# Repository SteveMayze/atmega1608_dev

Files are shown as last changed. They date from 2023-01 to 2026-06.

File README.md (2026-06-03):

# ATMega1608 Dev KiCad Automation

This project includes release automation for fabrication deliverables.

The automation entrypoints are intentionally stored at repository root so GitHub Actions can discover workflows correctly.

## Current automation goal

When a Git tag matching `r#.#.#` is pushed (example: `r0.1.0`), GitHub Actions will:

1. Set the KiCad text variable `RELEASE` in the project file.
2. Generate Gerber and drill files using `kicad-cli`.
3. Write deliverables to `gerber/`.
4. Upload artifacts and attach a ZIP to the GitHub release.

## Files added for automation

- `.github/workflows/release-gerbers.yml`: Release workflow triggered by version tags.
- `scripts/generate_release_artifacts.py`: Single entrypoint script for local and CI generation.
- `release-artifacts.json`: User-editable release configuration, including Gerber include layers.
- `PROJECT_TRACKING.md`: Task and roadmap tracking.

## Local usage

### Prerequisites

- KiCad installed with `kicad-cli` available on PATH.
- Python 3.9+.

If `kicad-cli` is not on PATH, set:

- macOS/Linux: `export KICAD_CLI=/full/path/to/kicad-cli`
- Windows (PowerShell): `$env:KICAD_CLI="C:\\Path\\To\\kicad-cli.exe"`

### Configure Gerber include layers

Edit `release-artifacts.json` and set:

- `project.path`: Relative path to your KiCad `.kicad_pro` file.
- `gerber.include_layers`: Layers to include in Gerber export.

Example:

```json
{
	"project": {
		"path": "kicad/ATMega1608_Dev/ATMega1608_Dev.kicad_pro"
	},
	"gerber": {
		"include_layers": [
			"F.Cu",
			"B.Cu",
			"F.Mask",
			"B.Mask",
			"F.SilkS",
			"B.SilkS",
			"Edge.Cuts"
		]
	}
}
```

This list is passed to `kicad-cli` as the `--layers` argument.
The script validates configured layer names against the board's `(layers ...)` list in the PCB file and fails early if any configured layer is invalid.

### Generate Gerbers for a release tag

```bash
python3 scripts/generate_release_artifacts.py --tag r0.1.0
```

This will update `RELEASE` to `0.1.0` and generate output in `gerber/`.

If needed, `--project` can still be passed to override `project.path` from config.

### Generate without updating `RELEASE`

```bash
python3 scripts/generate_release_artifacts.py --tag r0.1.0 --no-update-release-variable
```

### Dry run (no generation, just prints commands)

```bash
python3 scripts/generate_release_artifacts.py --tag r0.1.0 --dry-run
```

## Release trigger

Push a release tag:

```bash
git tag r0.1.0
git push origin r0.1.0
```

The workflow runs automatically for tags matching `r*.*.*`.

## CI KiCad version

This project currently targets a KiCad 10 board file format, so CI installs KiCad nightly in
GitHub Actions before generating artifacts.

The workflow uses `release-artifacts.json` for project discovery and does not hardcode the
`.kicad_pro` location.

## Future extension

The script already includes optional flags for future needs:

- `--schematic-pdf` to export schematic PDF.
- `--board-pdf` to export PCB layout PDF.

These are optional now and can be enabled later in the workflow.

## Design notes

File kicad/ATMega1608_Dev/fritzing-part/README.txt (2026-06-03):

KiCad2Fritzing conversion output
Source board: /Volumes/SanDisk/PCB-Archive/atmega1608_dev/kicad/ATMega1608_Dev/ATMega1608_Dev.kicad_pcb

Generated files:
  Intermediate model: board_model.json
  Connector model: fritzing_connectors.json
  Fritzing part definition: ATMega1608_Dev_260528_01d.fzp
  SVG views: icon.svg, breadboard.svg, schematic.svg, pcb.svg
  Fritzing shareable part: ATMega1608_Dev_260528_01d.fzpz (ready to import)
  Validation report: artifact_validation.json

To import into Fritzing:
  1. Open Fritzing
  2. Right-click in the 'Mine' bin → Import...
  3. Select ATMega1608_Dev_260528_01d.fzpz

Next step: refine SVG geometry from real board footprint data.

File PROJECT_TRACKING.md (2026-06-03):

# PROJECT_TRACKING

## Objective

Create a reusable release automation pattern for this KiCad project that can later be moved into a project template.

## Scope (current)

- [x] Add a single script entrypoint for fabrication deliverables.
- [x] Generate Gerber files with `kicad-cli`.
- [x] Generate drill files with `kicad-cli`.
- [x] Write outputs to `gerber/`.
- [x] Trigger generation from Git tag pattern `r#.#.#`.
- [x] Propagate release version from tag to KiCad text variable `RELEASE`.
- [x] Add user-configurable Gerber include layer list via JSON config.

## Scope (next)

- [ ] Export schematic PDF during release automation.
- [ ] Export PCB layout PDF during release automation.
- [ ] Add KiCad DRC/ERC checks in CI before artifact generation.
- [ ] Standardize artifact naming conventions for manufacturing handoff.

## Template readiness tasks

- [x] Move automation files into repository root locations required by GitHub Actions.
- [x] Parameterize project file name discovery for repositories where the KiCad project is not at root.
- [ ] Add a template onboarding checklist (toolchain, paths, variables).
- [ ] Document compatibility matrix for KiCad versions used in CI.

## Notes

- The source of truth for release version is the Git tag (`r#.#.#`).
- The script maps this tag to `RELEASE=#.#.#` in the `.kicad_pro` file before generation.
- This keeps release identity in one place while preserving KiCad text variable usage.

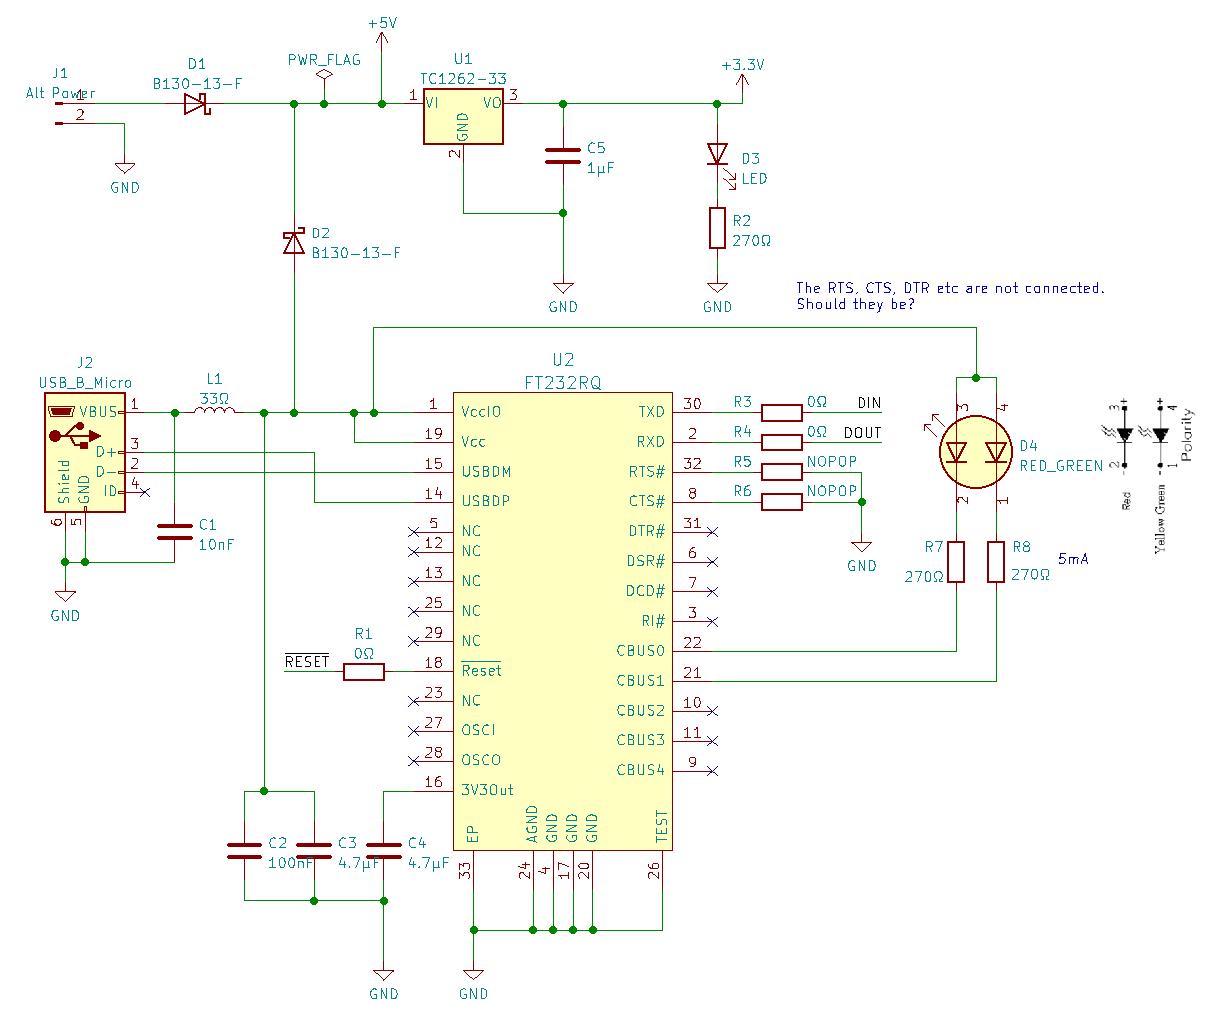
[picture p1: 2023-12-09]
kicad/doc/USART-Troubleshooting/FT232-Schematic.png

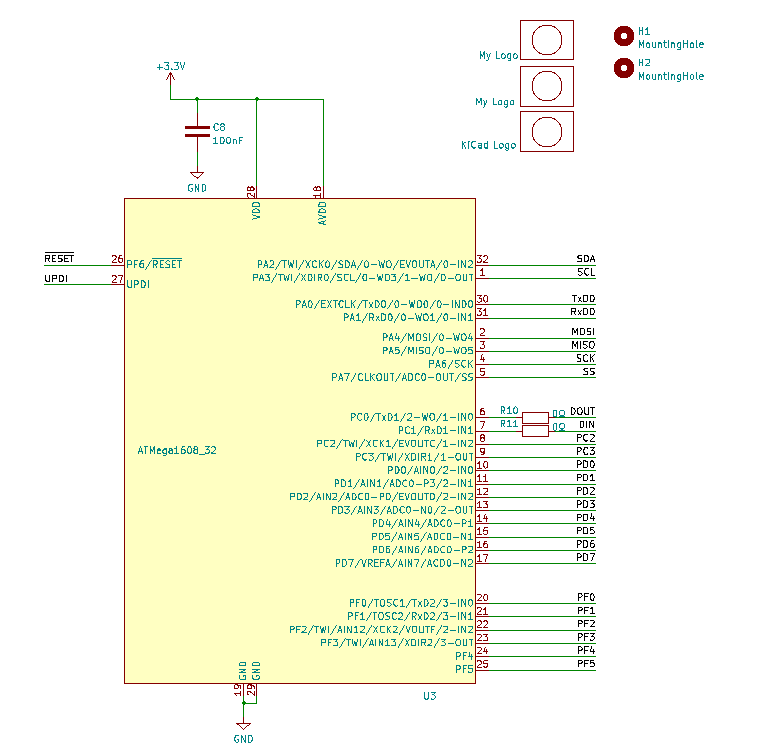
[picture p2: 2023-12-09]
kicad/doc/USART-Troubleshooting/MCU-Schematic.png

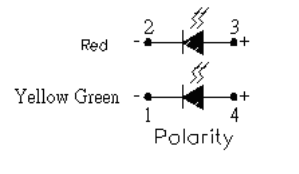
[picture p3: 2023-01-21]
kicad/doc/LED_Dual_KKAA.png

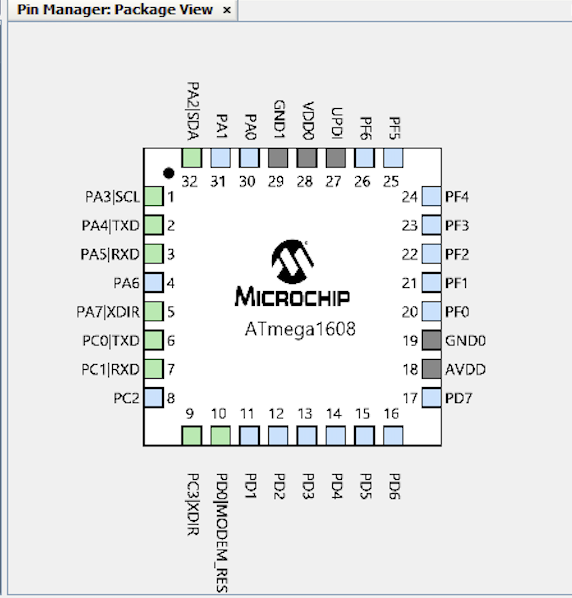
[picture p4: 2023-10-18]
kicad/doc/Atmega1608-Pins.png

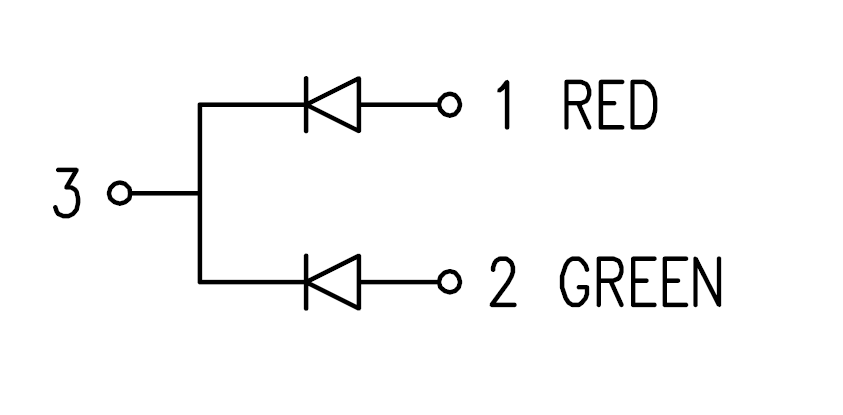
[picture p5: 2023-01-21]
kicad/doc/RGK_LED.png

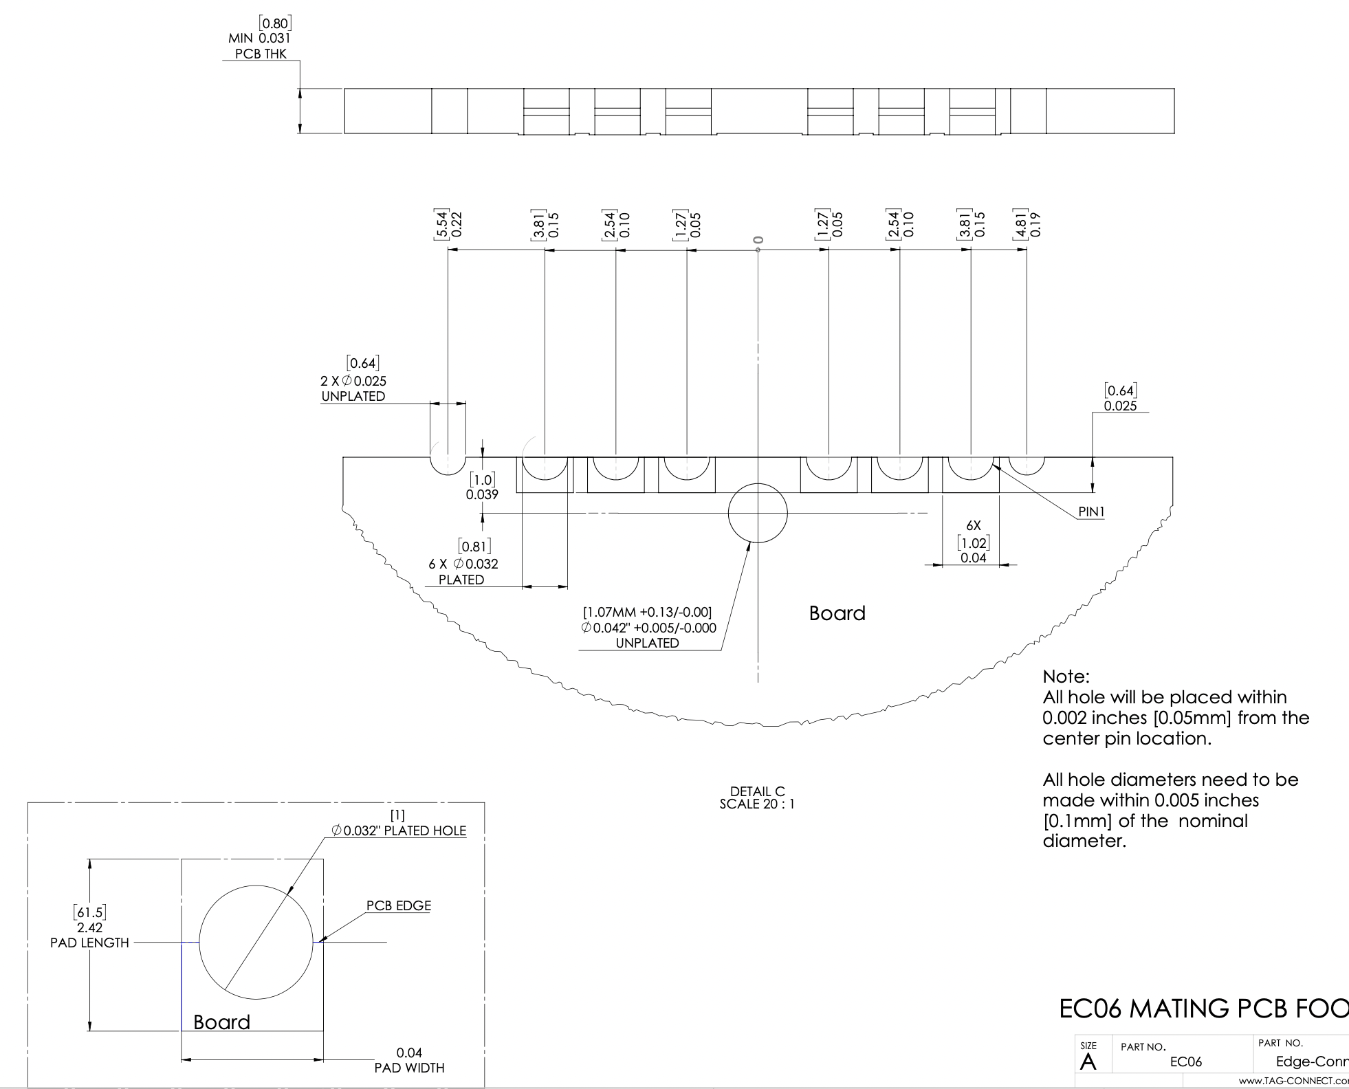
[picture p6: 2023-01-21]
kicad/doc/Screenshot 2022-12-26 at 10.46.26.png

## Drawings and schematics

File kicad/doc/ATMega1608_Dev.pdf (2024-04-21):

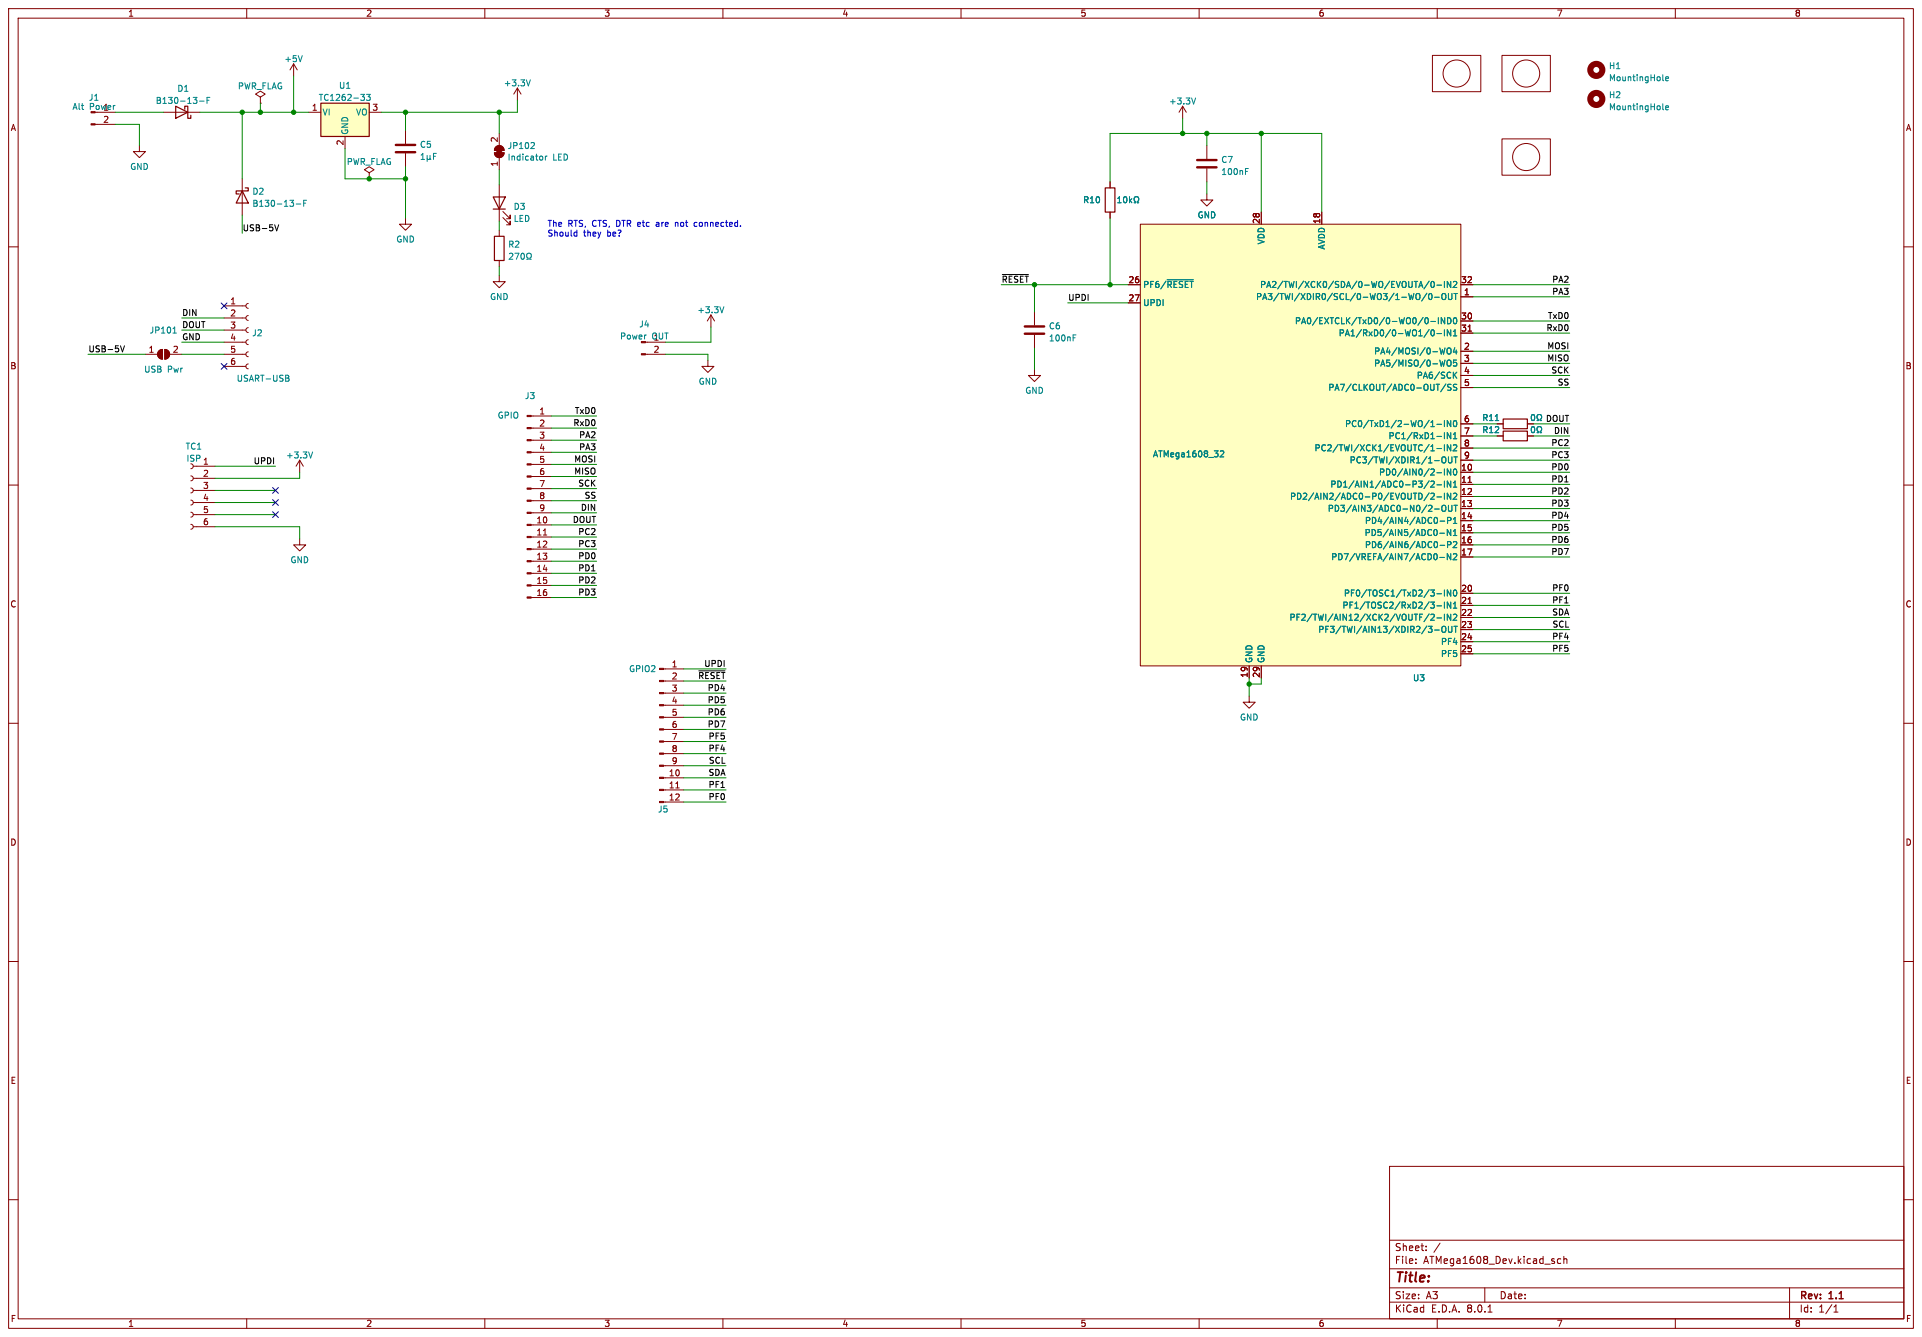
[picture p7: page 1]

Id: 1/1 Title: File: ATMega1608_Dev.kicad_sch Sheet: /

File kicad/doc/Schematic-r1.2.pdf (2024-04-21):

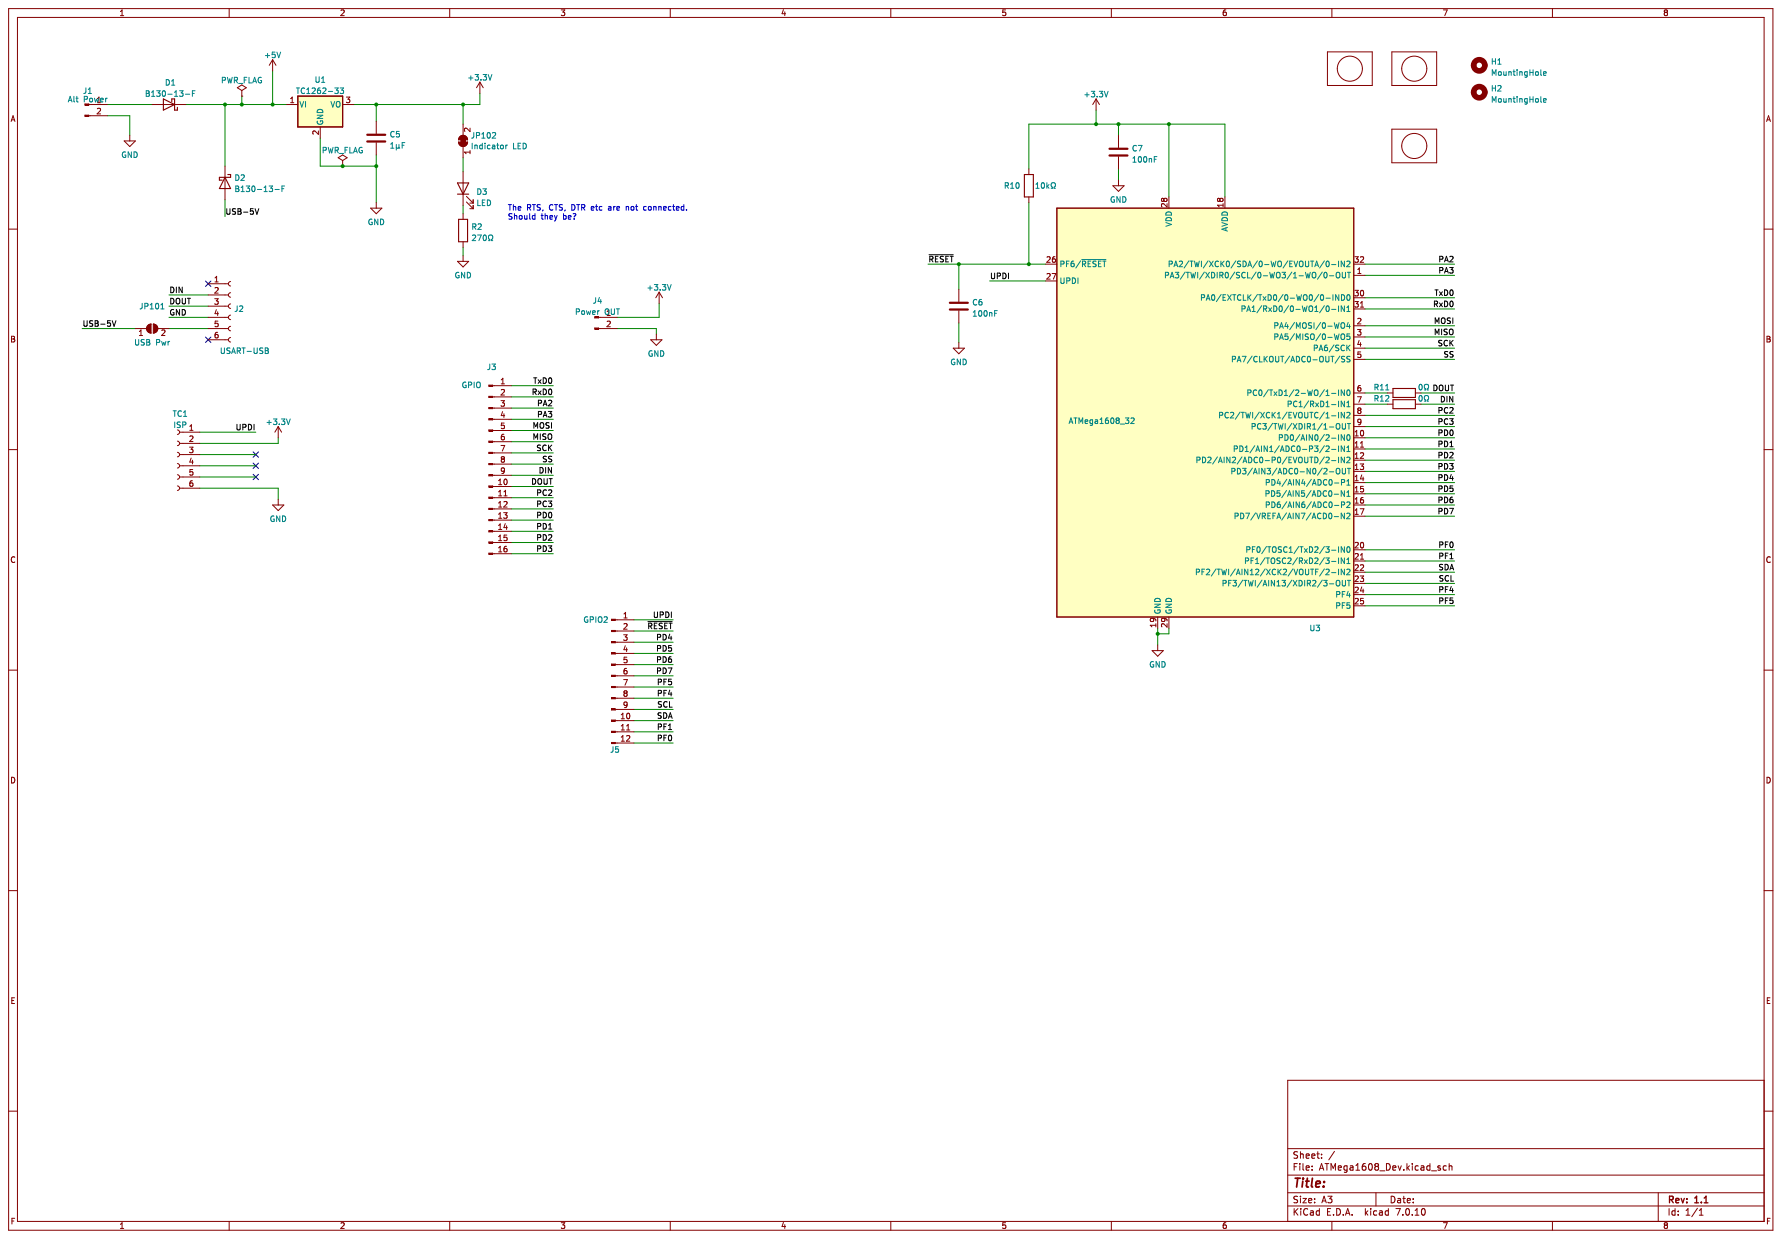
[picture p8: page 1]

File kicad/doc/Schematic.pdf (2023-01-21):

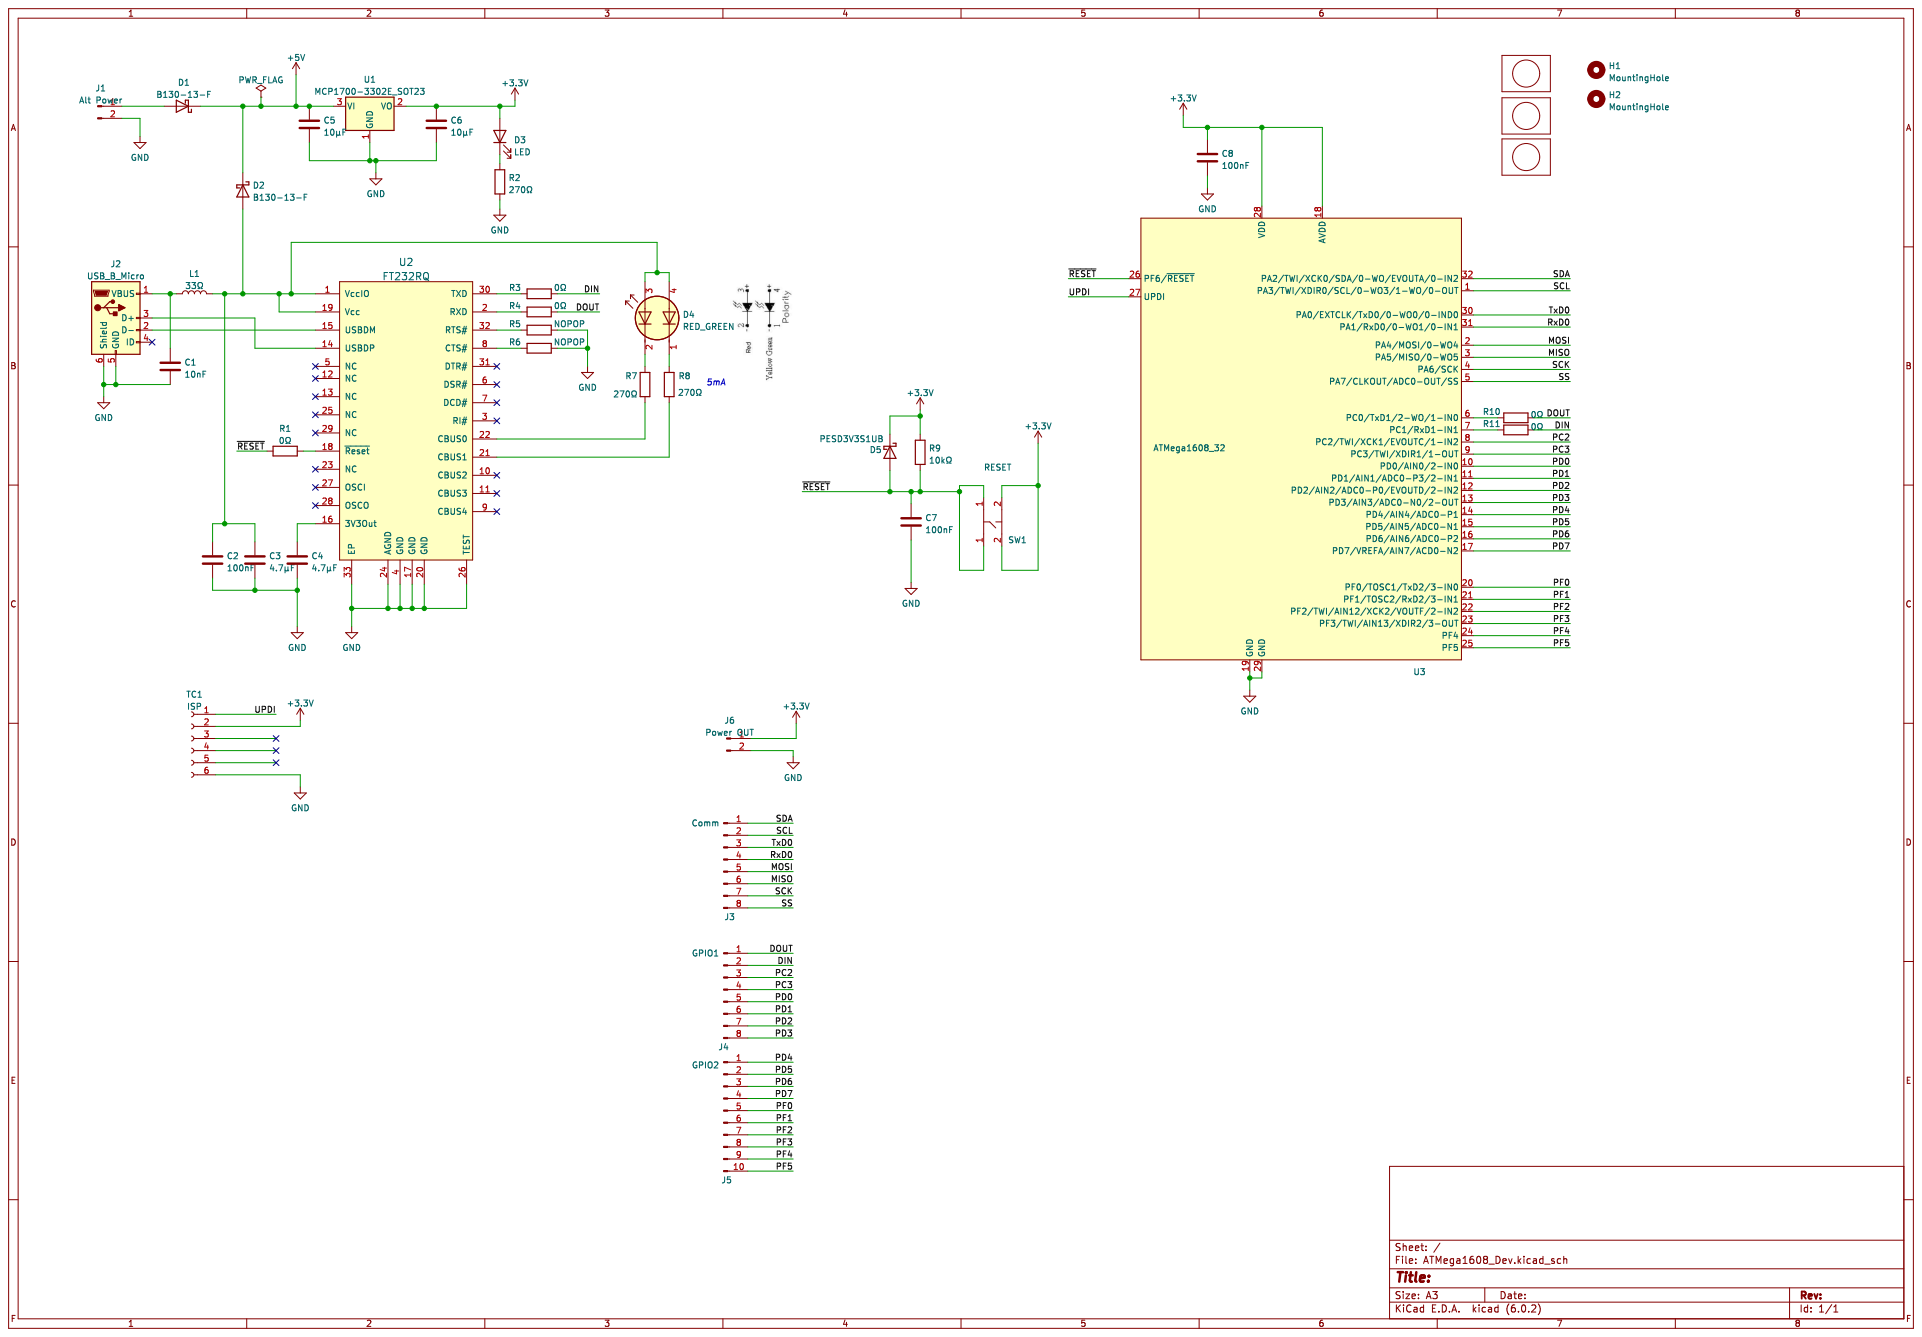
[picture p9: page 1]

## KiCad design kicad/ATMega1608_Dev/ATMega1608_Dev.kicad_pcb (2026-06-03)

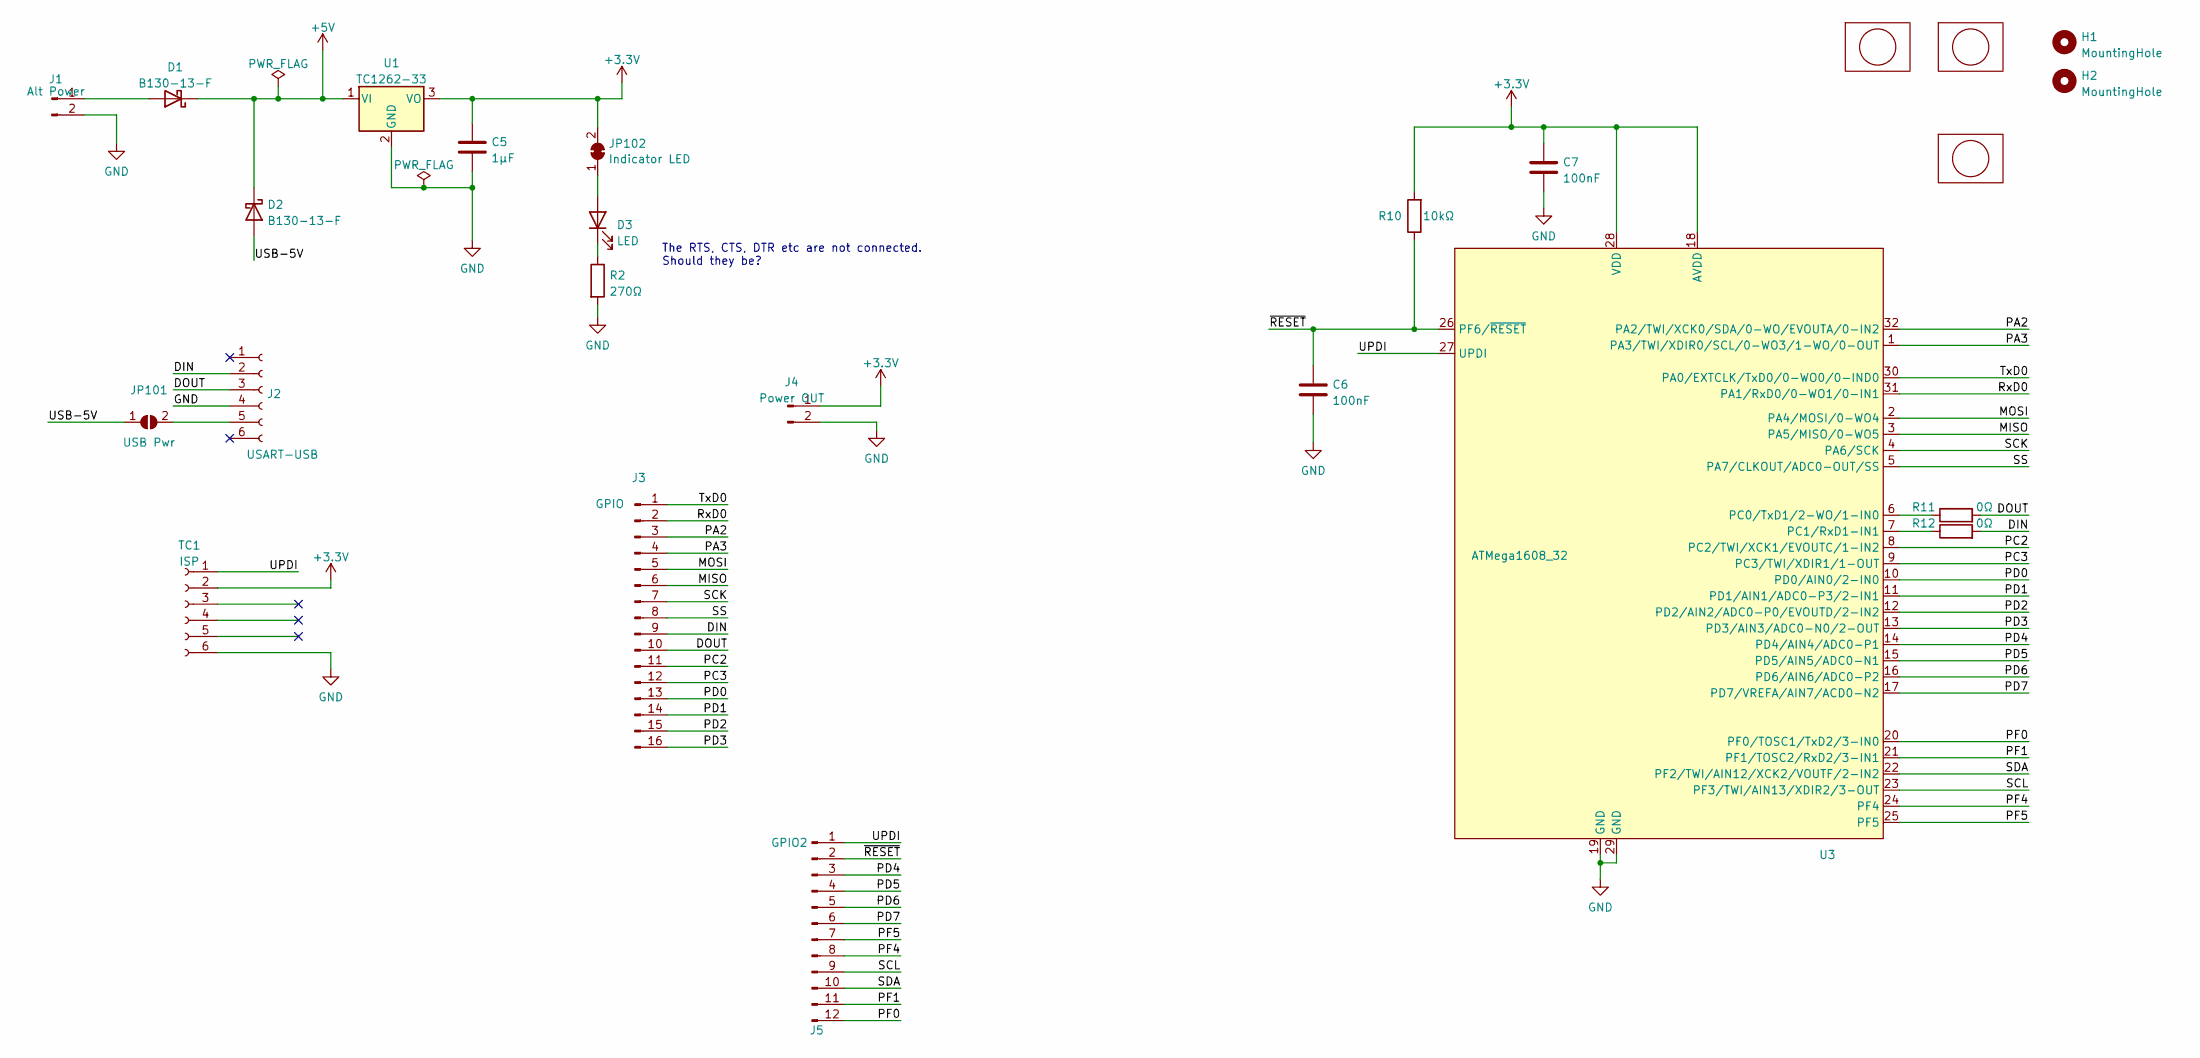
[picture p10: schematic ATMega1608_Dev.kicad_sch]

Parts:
C5: 1μF; C_0805_2012Metric_Pad1.18x1.45mm_HandSolder
C6, C7: 100nF; C_0805_2012Metric
D1, D2: B130-13-F; D_SMA; MPN B130-13-F
D3: LED; LED_0805_2012Metric
H1, H2: MountingHole; MountingHole_2.7mm_M2.5
J1: Alt Power; PinHeader_1x02_P2.54mm_Vertical
J2: USART-USB; PinSocket_1x06_P2.54mm_Vertical
J3: GPIO; PinHeader_1x16_P2.54mm_Vertical
J4: Power OUT; PinHeader_1x02_P2.54mm_Vertical
J5: GPIO2; PinHeader_1x12_P2.54mm_Vertical
JP101: USB Pwr; PinHeader_1x02_P2.54mm_Vertical
JP102: Indicator LED; SolderJumper-2_P1.3mm_Bridged_RoundedPad1.0x1.5mm
LG1, LG3: logo; MyBasic_rounded_50_1
LG2: logo; KiCad-Logo_5mm_SilkScreen
R2: 270Ω; R_0805_2012Metric
R10: 10kΩ; R_0805_2012Metric
R11, R12: 0Ω; R_0805_2012Metric
TC1: ISP; Tag-Connect EC06
U1: TC1262-33; SOT-223-3_TabPin2
U3: ATMega1608_32; TQFP-32_7x7mm_P0.8mm

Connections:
+3.3V: C5.1, C7.1, J4.1, JP102.2 (B), R10.2, TC1.2, U1.3 (VO), U3.18 (AVDD), U3.28 (VDD)
+5V: D1.1 (K), D2.1 (K), U1.1 (VI)
/DIN: J2.2, J3.9, R12.2
/DOUT: J2.3, J3.10, R11.2
/MISO: J3.6, U3.3 (PA5/MISO/0-WO5)
/MOSI: J3.5, U3.2 (PA4/MOSI/0-WO4)
/PA2: J3.3, U3.32 (PA2/TWI/XCK0/SDA/0-WO/EVOUTA/0-IN2)
/PA3: J3.4, U3.1 (PA3/TWI/XDIR0/SCL/0-WO3/1-WO/0-OUT)
/PC2: J3.11, U3.8 (PC2/TWI/XCK1/EVOUTC/1-IN2)
/PC3: J3.12, U3.9 (PC3/TWI/XDIR1/1-OUT)
/PD0: J3.13, U3.10 (PD0/AIN0/2-IN0)
/PD1: J3.14, U3.11 (PD1/AIN1/ADC0-P3/2-IN1)
/PD2: J3.15, U3.12 (PD2/AIN2/ADC0-P0/EVOUTD/2-IN2)
/PD3: J3.16, U3.13 (PD3/AIN3/ADC0-N0/2-OUT)
/PD4: J5.3, U3.14 (PD4/AIN4/ADC0-P1)
/PD5: J5.4, U3.15 (PD5/AIN5/ADC0-N1)
/PD6: J5.5, U3.16 (PD6/AIN6/ADC0-P2)
/PD7: J5.6, U3.17 (PD7/VREFA/AIN7/ACD0-N2)
/PF0: J5.12, U3.20 (PF0/TOSC1/TxD2/3-IN0)
/PF1: J5.11, U3.21 (PF1/TOSC2/RxD2/3-IN1)
/PF4: J5.8, U3.24 (PF4)
/PF5: J5.7, U3.25 (PF5)
/RxD0: J3.2, U3.31 (PA1/RxD0/0-WO1/0-IN1)
/SCK: J3.7, U3.4 (PA6/SCK)
/SCL: J5.9, U3.23 (PF3/TWI/AIN13/XDIR2/3-OUT)
/SDA: J5.10, U3.22 (PF2/TWI/AIN12/XCK2/VOUTF/2-IN2)
/SS: J3.8, U3.5 (PA7/CLKOUT/ADC0-OUT/SS)
/TxD0: J3.1, U3.30 (PA0/EXTCLK/TxD0/0-WO0/0-IND0)
/UPDI: J5.1, TC1.1, U3.27 (UPDI)
/USB-5V: D2.2 (A), JP101.1 (A)
/~RESET: C6.1, J5.2, R10.1, U3.26 (PF6/~RESET)
GND: C5.2, C6.2, C7.2, J1.2, J2.4, J4.2, R2.2, TC1.6, U1.2 (GND), U3.19 (GND), U3.29 (GND)
unnamed: D1.2 (A), J1.1
unnamed: D3.2 (A), JP102.1 (A)
unnamed: D3.1 (K), R2.1
unnamed: J2.5, JP101.2 (B)
unnamed: R11.1, U3.6 (PC0/TxD1/2-WO/1-IN0)
unnamed: R12.1, U3.7 (PC1/RxD1-IN1)

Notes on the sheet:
The RTS, CTS, DTR etc are not connected. Should they be?

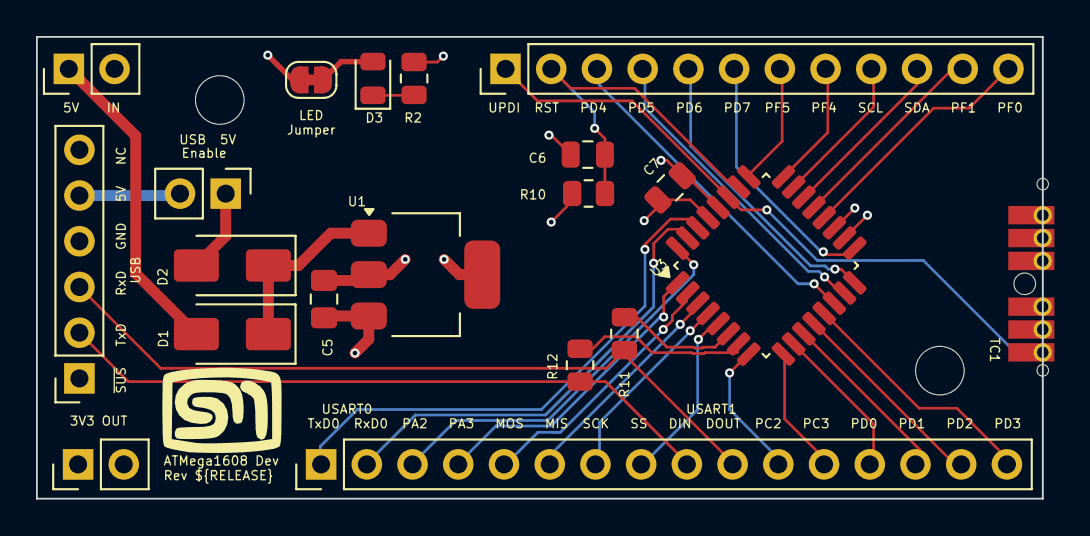
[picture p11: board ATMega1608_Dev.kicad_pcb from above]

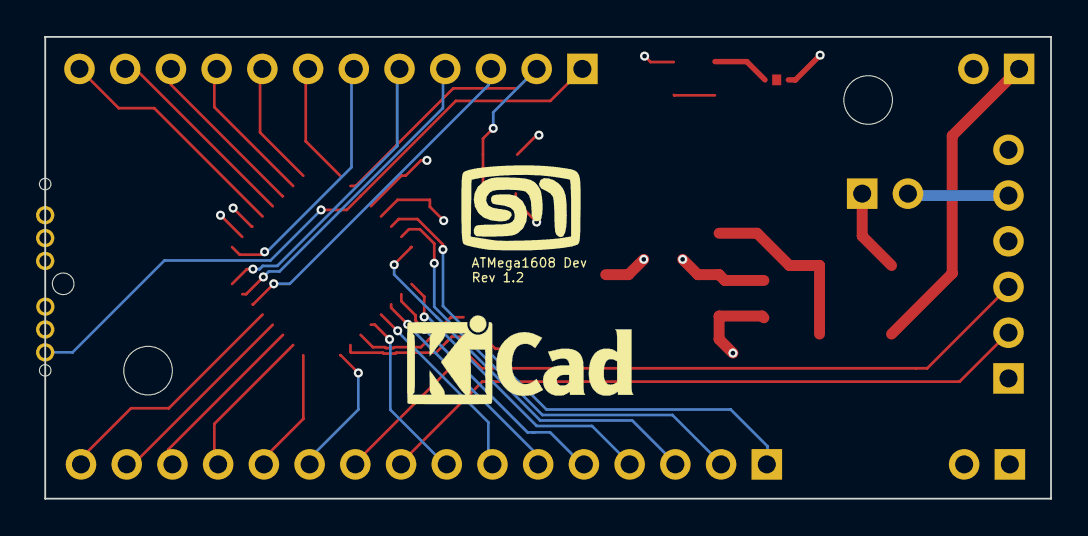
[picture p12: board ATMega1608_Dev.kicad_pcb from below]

Board: 4 copper layers, 55.9 x 25.7 mm, 25 parts (2 on the bottom side), 38 nets.

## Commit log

2023-01-21 Initial checkin
    [ATMega1608_Dev.kicad_pcb, ATMega1608_Dev.kicad_sch]
2023-01-21 Schematic complete
    [ATMega1608_Dev.kicad_sch]
2023-01-21 Started on the layout
    [ATMega1608_Dev.kicad_pcb, ATMega1608_Dev.kicad_sch]
2023-01-22 The layout is complete - pending verification of USB interface
    [ATMega1608_Dev.kicad_pcb, ATMega1608_Dev.kicad_sch]
2023-03-05 Fixes some labeling issues
    [ATMega1608_Dev.kicad_pcb, ATMega1608_Dev.kicad_sch]
2023-10-18 Adds pin allocation images
2023-11-05 Fixes label overflow
    [ATMega1608_Dev.kicad_pcb, ATMega1608_Dev.kicad_sch]
2023-12-09 Revert "Fixes label overflow"
    This reverts commit 462388ed25e35246e7662647474ba0507c06f5b0.
    [ATMega1608_Dev.kicad_pcb, ATMega1608_Dev.kicad_sch]
2023-12-09 Moved the USART_Troubleshooting changes to main
    [ATMega1608_Dev.kicad_pcb, ATMega1608_Dev.kicad_sch]
2024-01-14 Revision 1.2 - Update to connectors, jumpers and labels
    [ATMega1608_Dev.kicad_pcb, ATMega1608_Dev.kicad_sch]
2024-04-21 Revision 1.2
    [ATMega1608_Dev.kicad_sch]
2026-06-03 Adding a PCB release workflow
    [ATMega1608_Dev-B_Cu.gbl, ATMega1608_Dev-B_Mask.gbs, ATMega1608_Dev-B_Paste.gbp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]
2026-06-03 Update gerber release to use nightly
2026-06-03 Prefix the project name to the gerber zip file for the release
2026-06-03 Removed the obolete gerber directory
    [ATMega1608_Dev-B_Cu.gbl, ATMega1608_Dev-B_Mask.gbs, ATMega1608_Dev-B_Paste.gbp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]
2026-08-10 Adds version tracking for the gerber generation action scripts
